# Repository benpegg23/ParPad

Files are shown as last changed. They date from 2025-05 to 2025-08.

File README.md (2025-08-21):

# ⛳ ParPad

**ParPad** is an STM32-based macropad featuring a 3×3 layout and two rotary encoders. Custom firmware coming soon! 

## 🔧 Features

- 3×3 mechanical key matrix
- Dual EC11 rotary encoders with push functionality
- Cherry MX switch support
- USB-C connectivity
- STM32F072C8T6 Microcontroller
- Custom firmware (coming soon)

## 📸 Images

parpadbannersidestuff
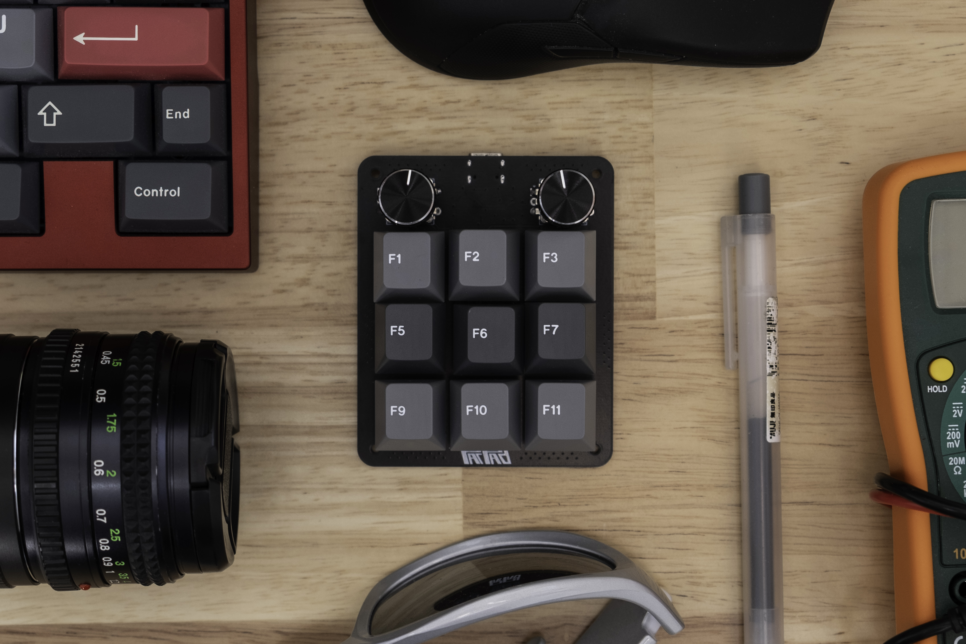
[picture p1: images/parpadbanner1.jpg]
parpadbanner1

parpad1
parpadbelow
parpad_down
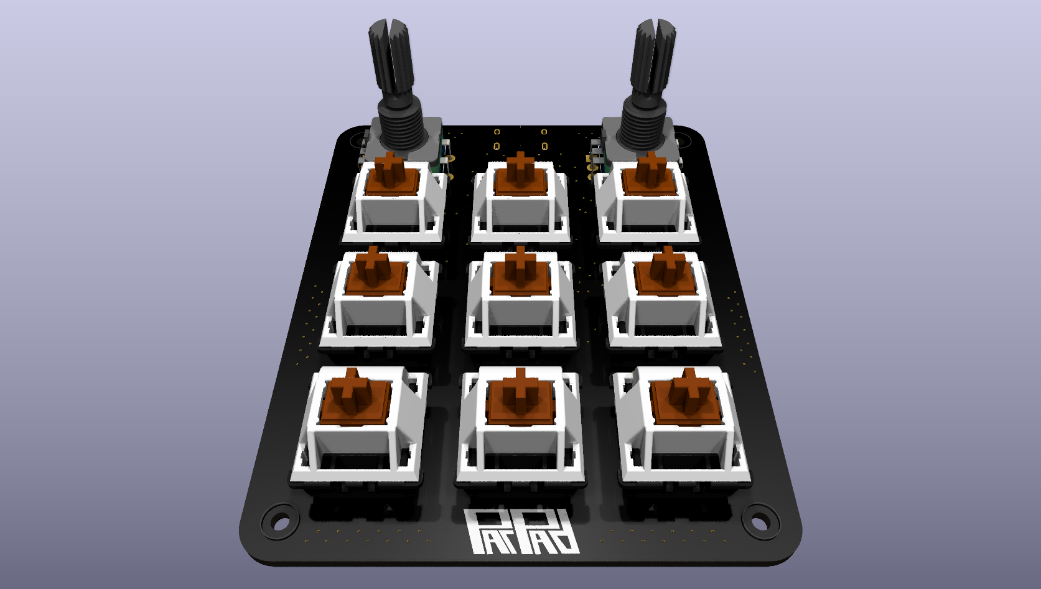
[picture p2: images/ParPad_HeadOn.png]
ParPad_HeadOn

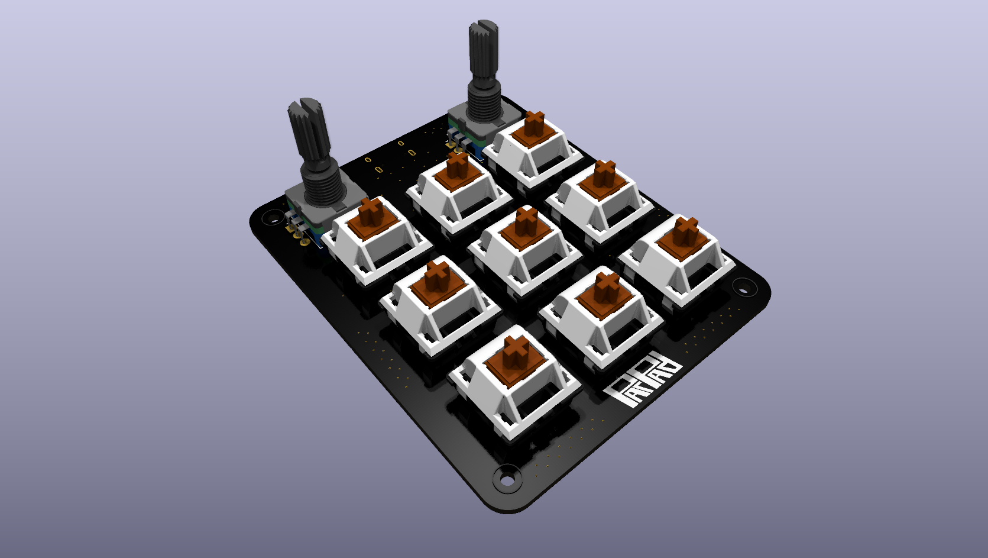
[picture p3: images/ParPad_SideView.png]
ParPad_SideView

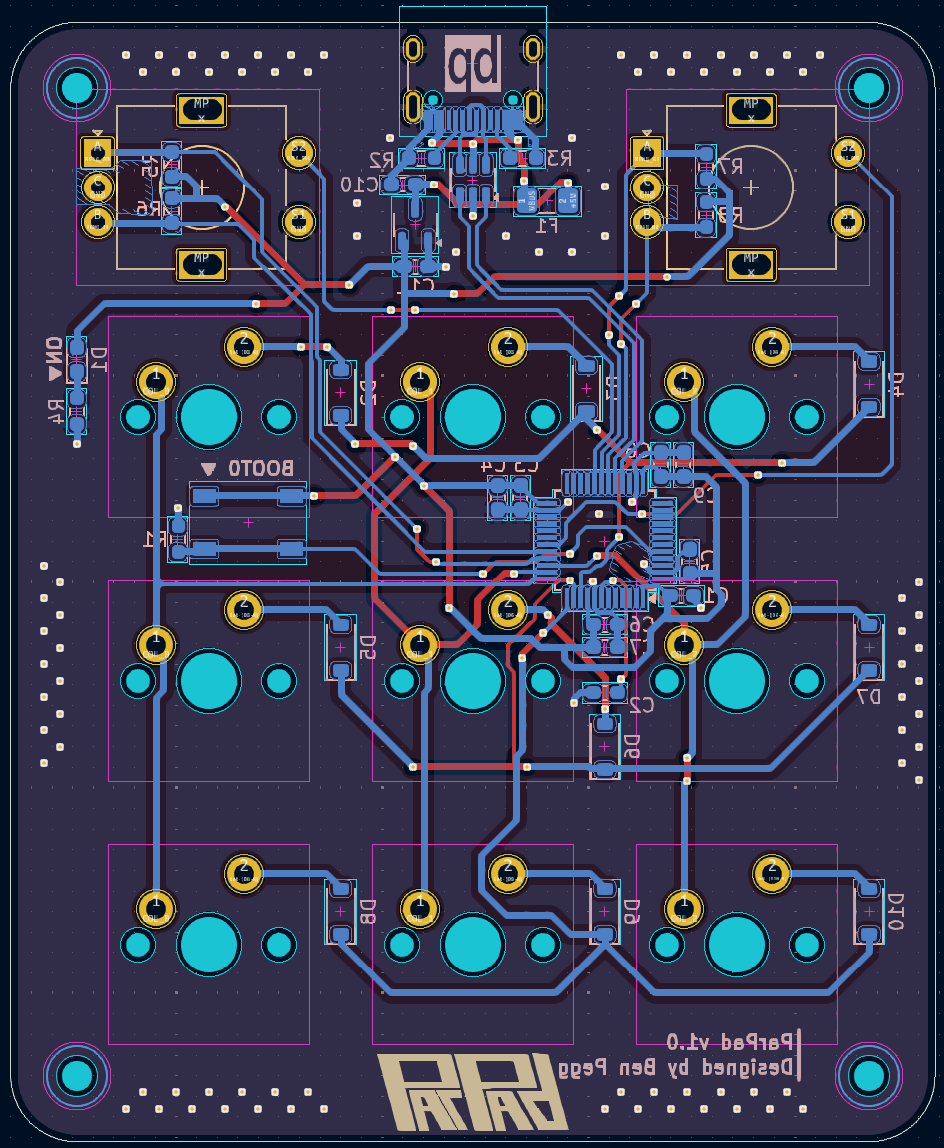
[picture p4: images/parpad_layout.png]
parpad_layout


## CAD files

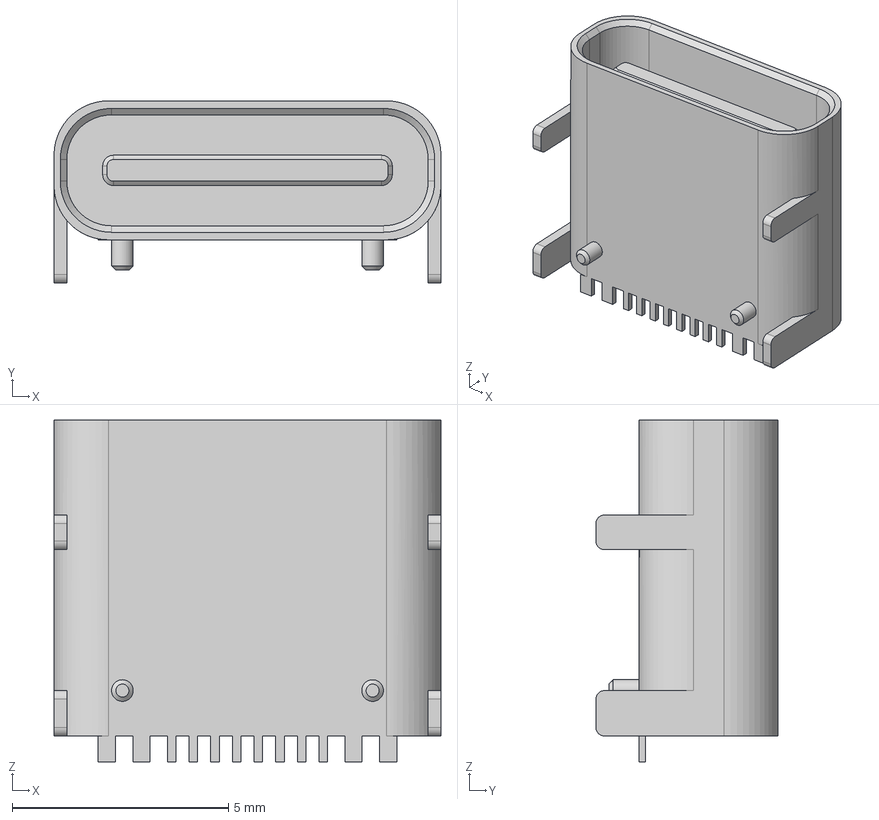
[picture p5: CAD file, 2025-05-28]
hardware/macropad_v1.0/3d_models/HRO TYPE-C-31-M-12_ai03.step
8.94 x 4.21 x 7.90 mm

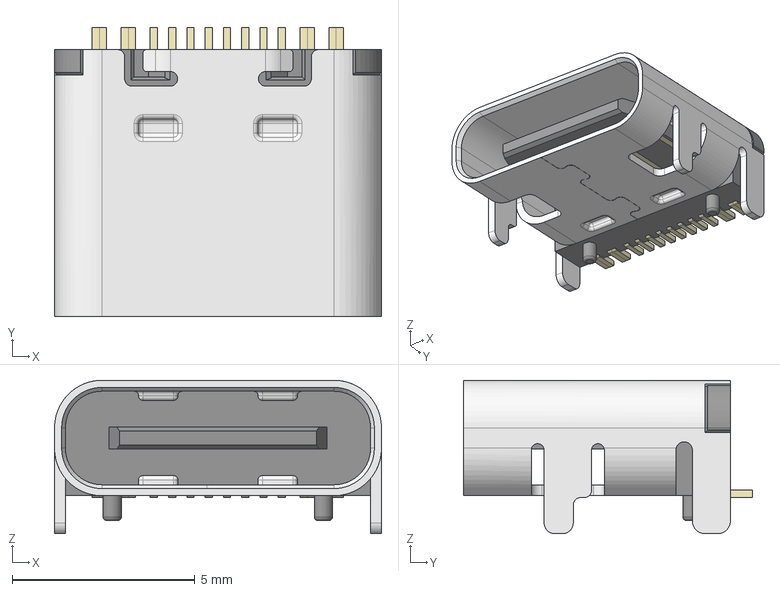
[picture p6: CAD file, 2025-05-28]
hardware/macropad_v1.0/3d_models/HRO_TYPE-C-31-M-12.step
8.95 x 7.90 x 4.20 mm

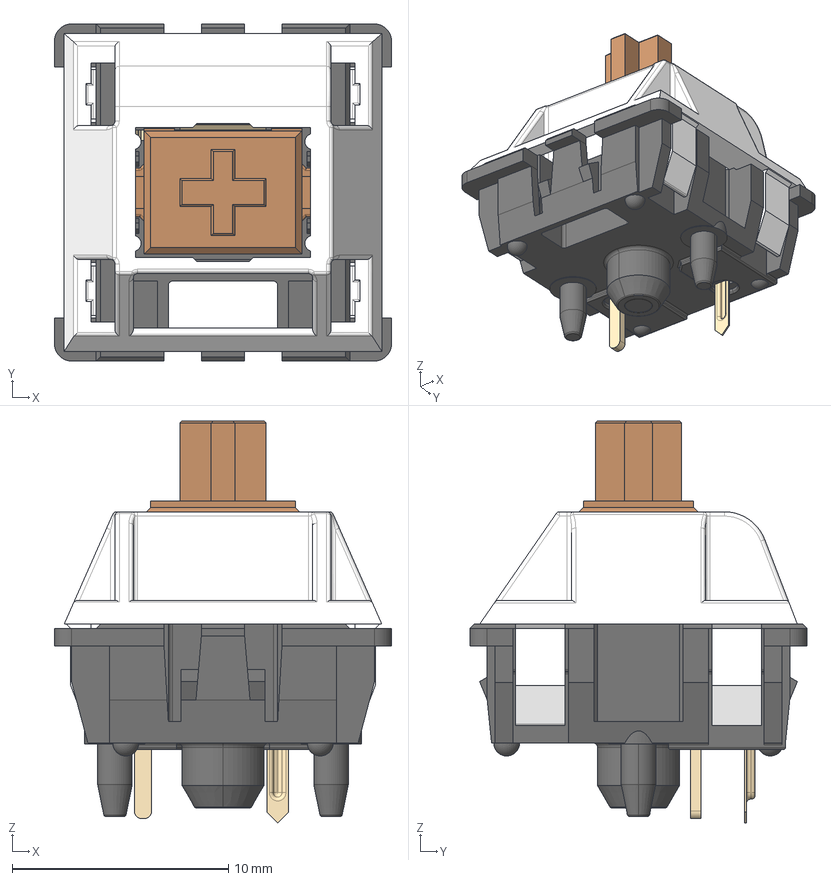
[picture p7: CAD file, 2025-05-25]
hardware/macropad_v1.0/3d_models/MX_PCB.step
15.6 x 15.6 x 18.6 mm

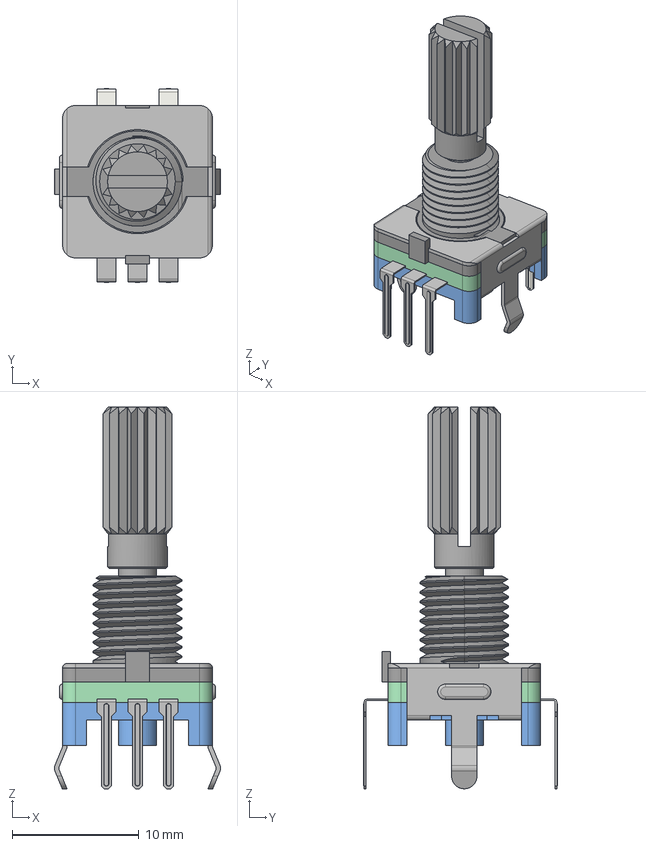
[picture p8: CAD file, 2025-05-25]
hardware/macropad_v1.0/3d_models/EC11_Rotary_Encoder_Switched.step
13.1 x 15.3 x 30.1 mm

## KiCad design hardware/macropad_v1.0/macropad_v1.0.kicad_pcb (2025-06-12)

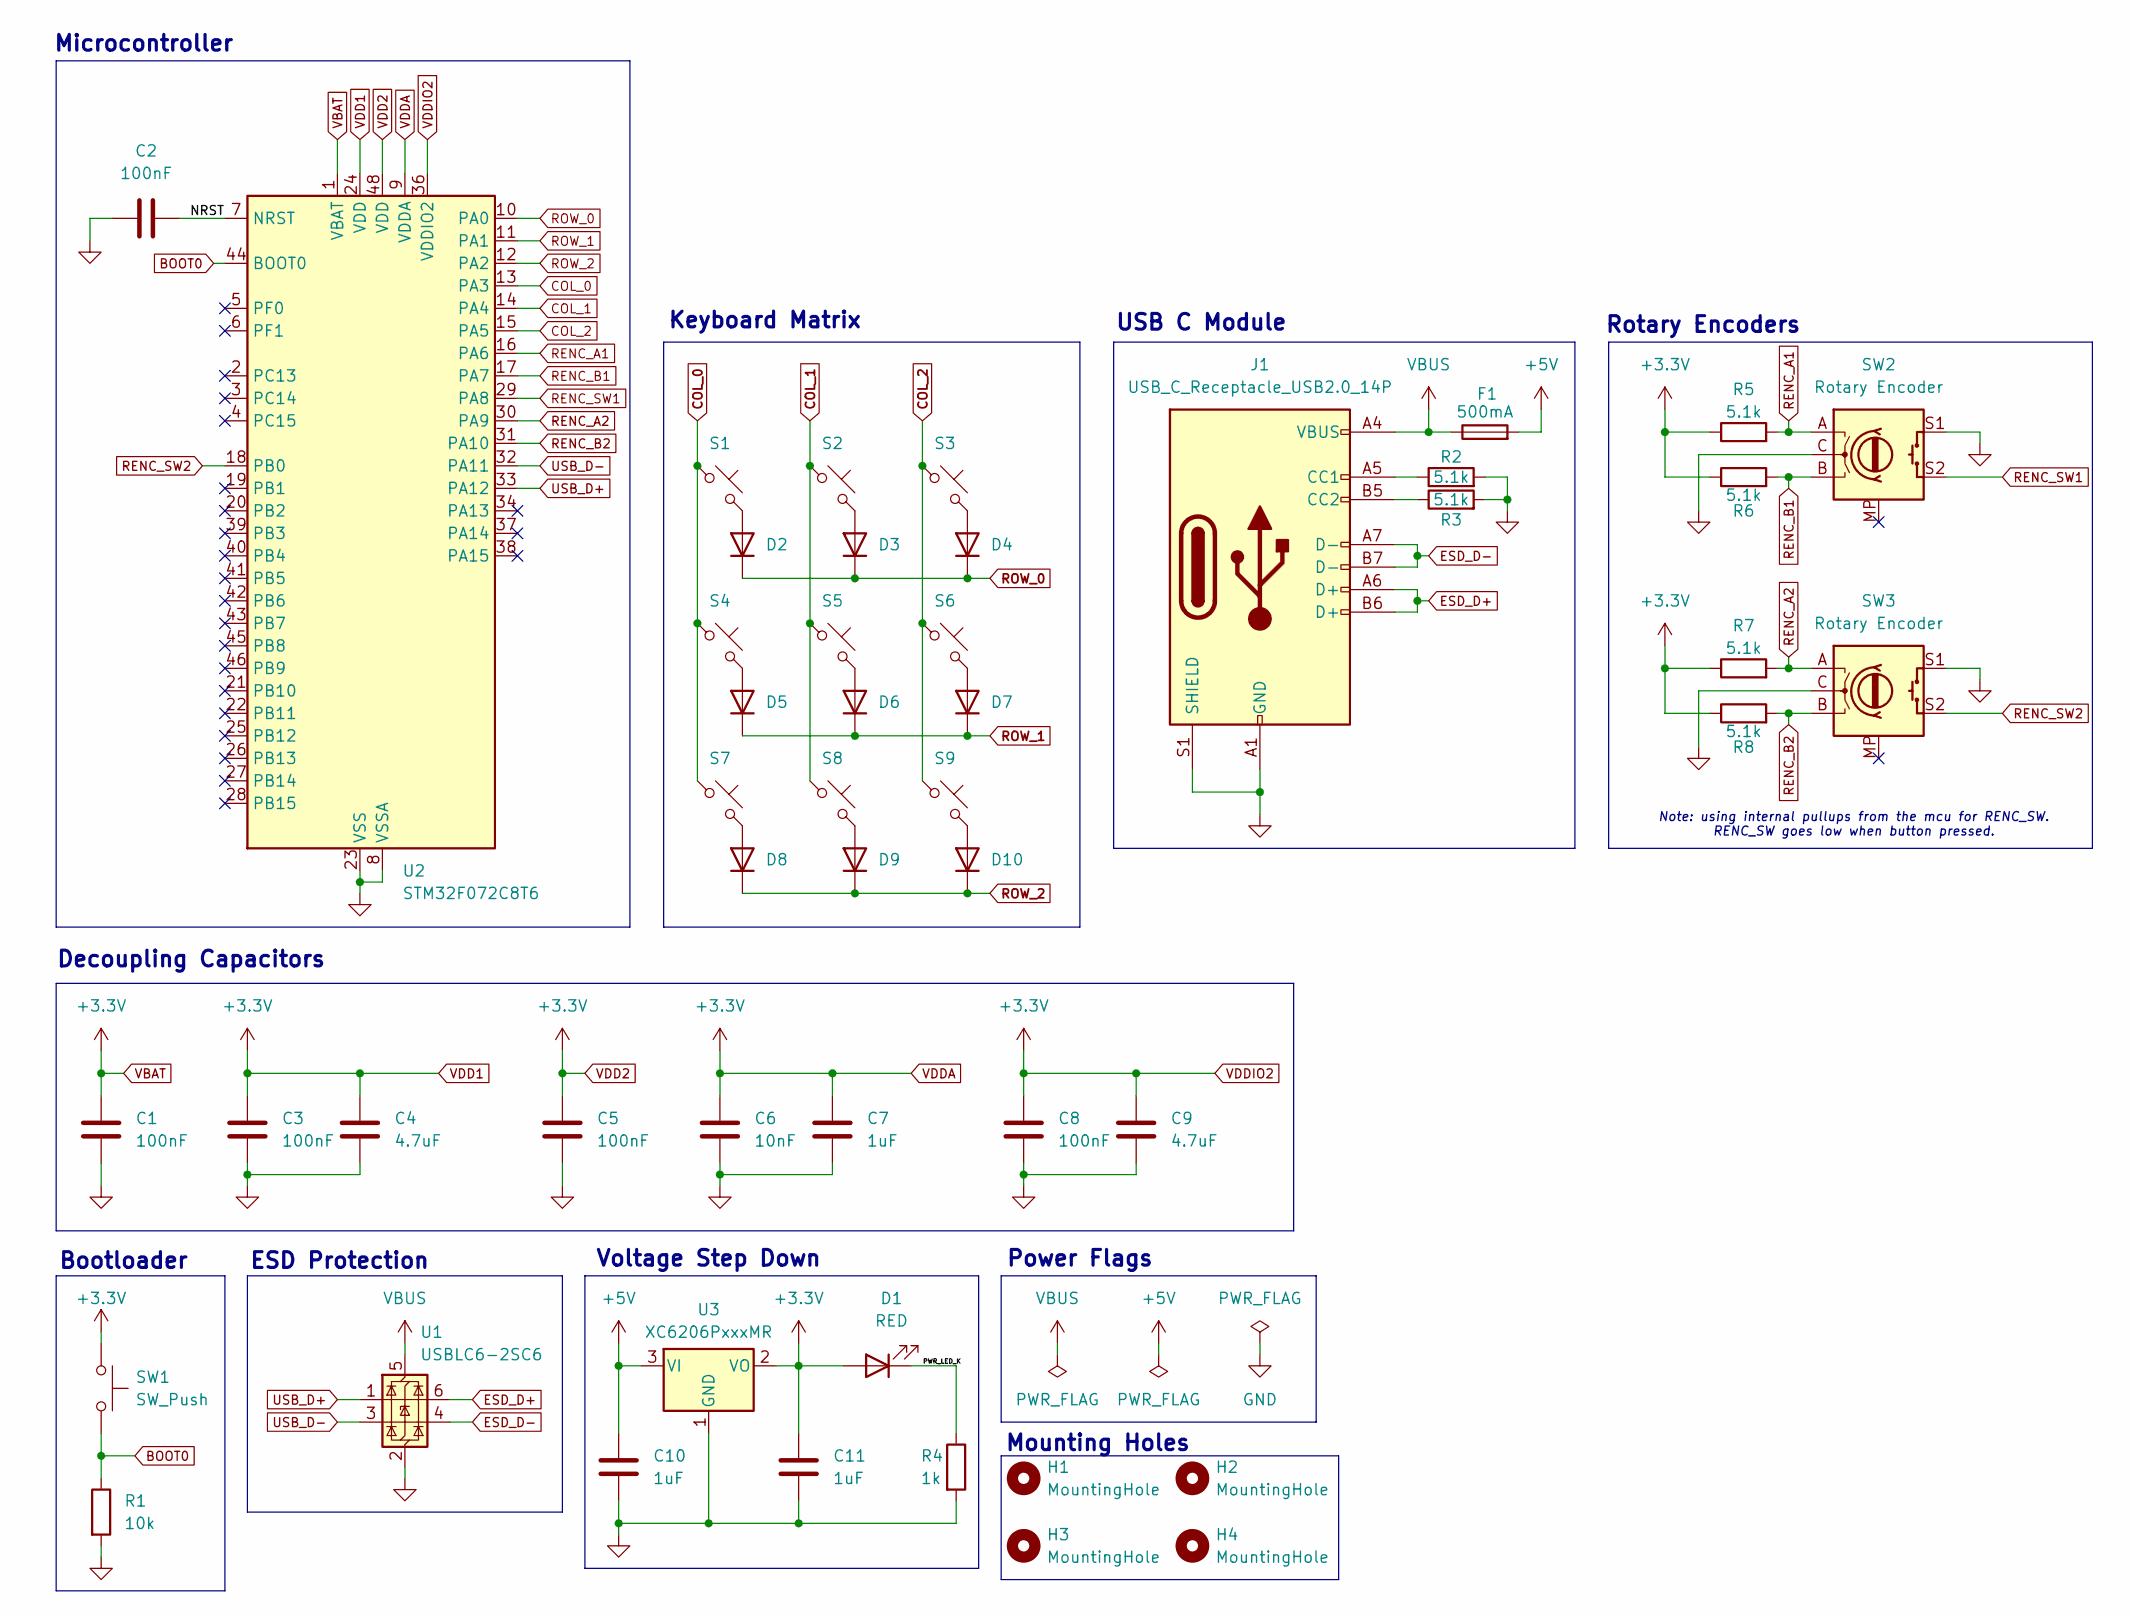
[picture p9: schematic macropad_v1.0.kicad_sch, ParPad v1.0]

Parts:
C1, C2, C3, C5, C8: 100nF; C_0603_1608Metric_Pad1.08x0.95mm_HandSolder
C4, C9: 4.7uF; C_0603_1608Metric_Pad1.08x0.95mm_HandSolder
C6: 10nF; C_0603_1608Metric_Pad1.08x0.95mm_HandSolder
C7, C10, C11: 1uF; C_0603_1608Metric_Pad1.08x0.95mm_HandSolder
D1: RED; LED_0603_1608Metric_Pad1.05x0.95mm_HandSolder
D2, D3, D4, D5, D6, D7, D8, D9, D10: 1N4148W; D_SOD-123
F1: 500mA; Fuse_1206_3216Metric_Pad1.42x1.75mm_HandSolder
H1, H2, H3, H4: MountingHole; MountingHole_2.2mm_M2
J1: USB_C_Receptacle_USB2.0_14P; USB_C_Receptacle_HRO_TYPE-C-31-M-12
R1: 10k; R_0603_1608Metric_Pad0.98x0.95mm_HandSolder
R2, R3, R5, R6, R7, R8: 5.1k; R_0603_1608Metric_Pad0.98x0.95mm_HandSolder
R4: 1k; R_0603_1608Metric_Pad0.98x0.95mm_HandSolder
S1, S2, S3, S4, S5, S6, S7, S8, S9: Keyswitch; MX_PCB_1.00u
SW1: SW_Push; Button_TL3342
SW2, SW3: Rotary Encoder; RotaryEncoder_Alps_EC11E-Switch_Vertical_H20mm
U1: USBLC6-2SC6; SOT-23-6
U2: STM32F072C8T6; LQFP-48_7x7mm_P0.5mm
U3: XC6206PxxxMR; SOT-23-3

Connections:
+5V: C10.1, F1.2, U3.3 (VI)
/NRST: C2.2, U2.7 (NRST)
/PWR_LED_K: D1.1 (K), R4.1
BOOT0: R1.1, SW1.2, U2.44 (BOOT0)
COL_0: S1.1, S4.1, S7.1, U2.13 (PA3)
COL_1: S2.1, S5.1, S8.1, U2.14 (PA4)
COL_2: S3.1, S6.1, S9.1, U2.15 (PA5)
ESD_D+: J1.A6 (D+), J1.B6 (D+), U1.6 (I/O1)
ESD_D-: J1.A7 (D-), J1.B7 (D-), U1.4 (I/O2)
GND: C1.2, C2.1, C3.2, C4.2, C5.2, C6.2, C7.2, C8.2, C9.2, C10.2, C11.2, J1.A1 (GND), J1.A12 (GND), J1.B1 (GND), J1.B12 (GND), J1.S1 (SHIELD), R1.2, R2.2, R3.2, R4.2, SW2.C, SW2.S1, SW3.C, SW3.S1, U1.2 (GND), U2.8 (VSSA), U2.23 (VSS), U2.35 (VSS), U2.47 (VSS), U3.1 (GND)
unnamed: D2.2 (A), S1.2
unnamed: D3.2 (A), S2.2
unnamed: D4.2 (A), S3.2
unnamed: D5.2 (A), S4.2
unnamed: D6.2 (A), S5.2
unnamed: D7.2 (A), S6.2
unnamed: D8.2 (A), S7.2
unnamed: D9.2 (A), S8.2
unnamed: D10.2 (A), S9.2
unnamed: J1.A5 (CC1), R2.1
unnamed: J1.B5 (CC2), R3.1
RENC_A1: R5.2, SW2.A, U2.16 (PA6)
RENC_A2: R7.2, SW3.A, U2.30 (PA9)
RENC_B1: R6.2, SW2.B, U2.17 (PA7)
RENC_B2: R8.2, SW3.B, U2.31 (PA10)
RENC_SW1: SW2.S2, U2.29 (PA8)
RENC_SW2: SW3.S2, U2.18 (PB0)
ROW_0: D2.1 (K), D3.1 (K), D4.1 (K), U2.10 (PA0)
ROW_1: D5.1 (K), D6.1 (K), D7.1 (K), U2.11 (PA1)
ROW_2: D8.1 (K), D9.1 (K), D10.1 (K), U2.12 (PA2)
USB_D+: U1.1 (I/O1), U2.33 (PA12)
USB_D-: U1.3 (I/O2), U2.32 (PA11)
VBAT: C1.1, C3.1, C4.1, C5.1, C6.1, C7.1, C8.1, C9.1, C11.1, D1.2 (A), R5.1, R6.1, R7.1, R8.1, SW1.1, U2.1 (VBAT), U2.9 (VDDA), U2.24 (VDD), U2.36 (VDDIO2), U2.48 (VDD), U3.2 (VO)
VBUS: F1.1, J1.A4 (VBUS), J1.A9 (VBUS), J1.B4 (VBUS), J1.B9 (VBUS), U1.5 (VBUS)

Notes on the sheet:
Note: using internal pullups from the mcu for RENC_SW. RENC_SW goes low when button pressed.
Voltage Step Down
Keyboard Matrix
Bootloader
Rotary Encoders
Decoupling Capacitors
ESD Protection
Power Flags
USB C Module
Mounting Holes
Microcontroller

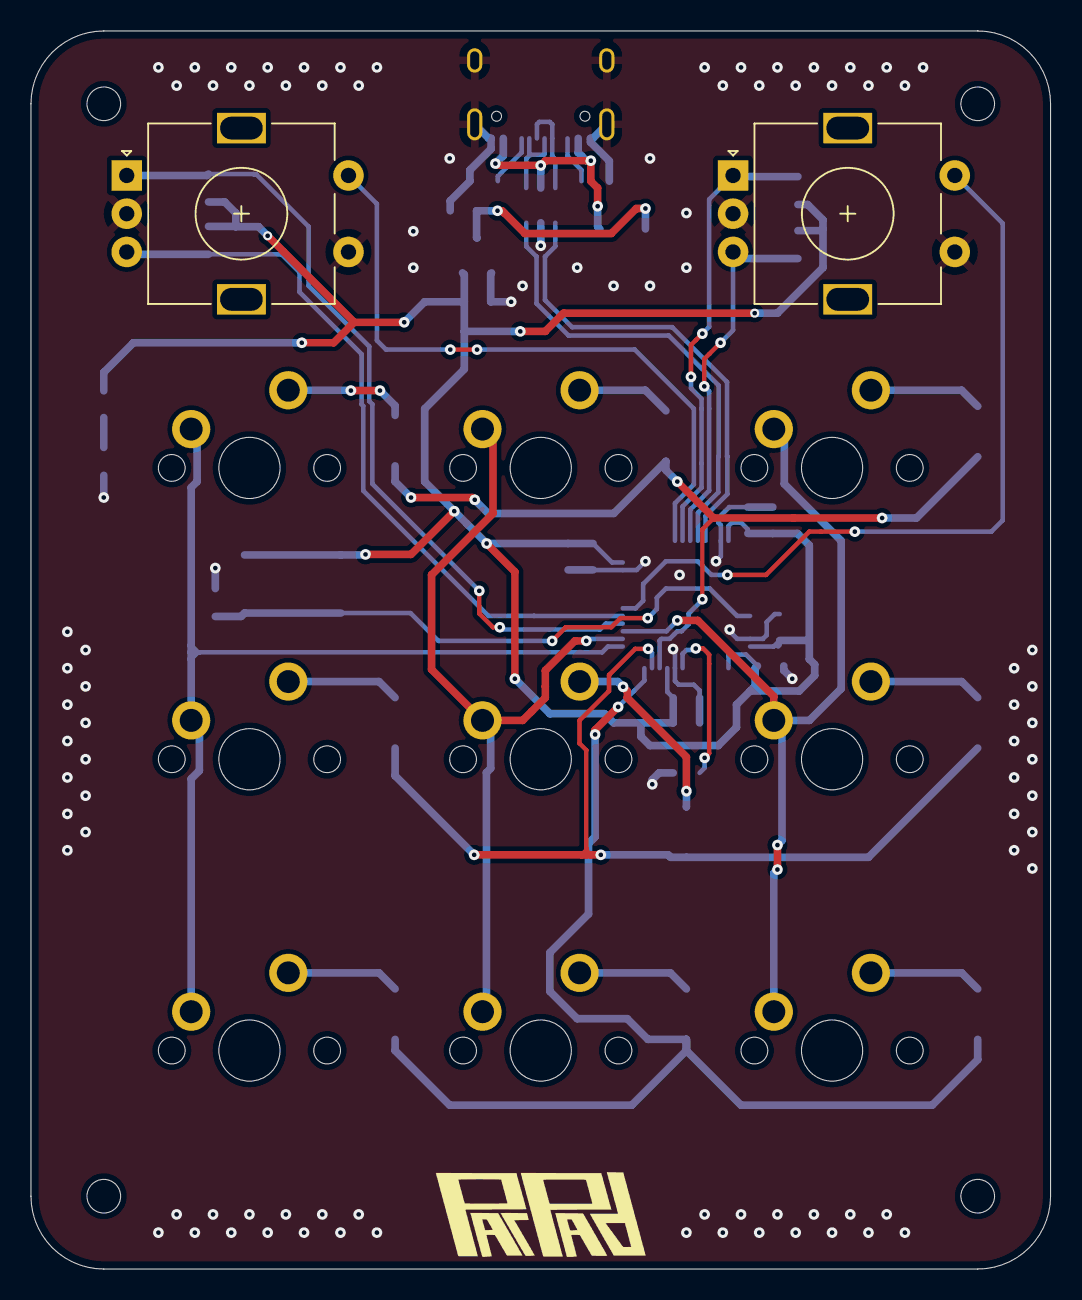
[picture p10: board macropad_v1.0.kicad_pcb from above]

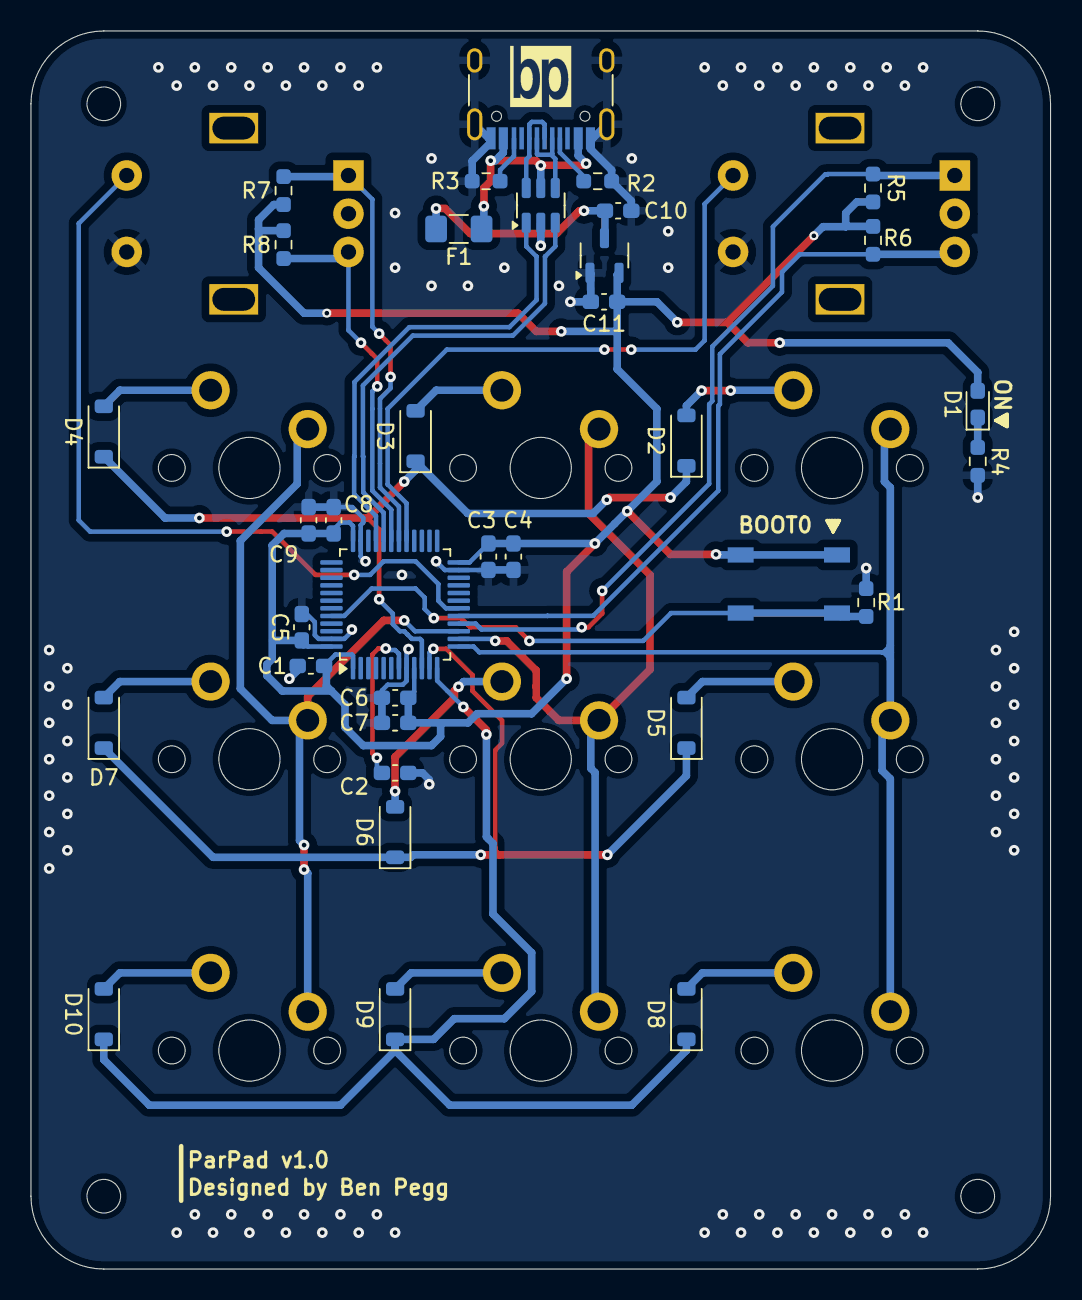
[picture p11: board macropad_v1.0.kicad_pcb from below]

Board: 2 copper layers, 66.7 x 81.0 mm, 50 parts (35 on the bottom side), 34 nets.

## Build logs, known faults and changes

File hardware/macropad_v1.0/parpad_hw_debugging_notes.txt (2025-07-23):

Issues when assembling:
- 3v3 led indicator turns on for a split second when connecting, and then shuts off. Probing reveals that the board is receiving 5v correctly, but something is happening with the voltage regulator, because Vout is around 0.5v instead of the expected 3v3. 
--Potential Reasons: 
--datasheet config shows diodes included on 3v3 and 5v sides, but iirc they're not essential?
--probably a short somewhere that's connecting 3v3 and gnd
--if can't find short, try replacing voltage regulator unit
- Definitely a short somewhere, when doing a continuity test between ground and 3v3 output of voltage regulator, getting a beep. Also lifehack, you can use the outside of the usb connector as a ground reference. 
- Tried to find short using the resistance method thing where you measure the resistance between gnd and 3v3 path. Apparently the resistance is supposed to decrease when you're getting closer to the short, but when measuring it, all of the resistance measurements were the same across the whole 3v3 path. Probably because my multimeter isn't accurate enough to find the small changes, would need a bench multimeter. 
- Best way to find a short is to use a bench power supply, which I obviously don't have
-- Connect power supply, set to ~1-2V, set current to around 5-10A, attach to 3v3 rail, then see which component gets hot
-- Can either use finger, isopropyl alcohol (see where evaporates first), or thermal camera
- Other way is to just desolder components until you find the short, which is prob what I'll have to do cuz I otherwise I have to wait a month until I get back to school.

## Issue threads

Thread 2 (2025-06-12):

find a usb-c receptacle

benpegg23, 2025-06-12:
I need a hand solderable usb-c receptacle that isn't hella expensive and matches the footprint of the HRO version cuz digikey doesn't have it 😔

Closed 2025-06-14.

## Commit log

2025-05-25 pushing initial design of schematic, updated project file structure
    [EC11_Rotary_Encoder_Switched.step, MX_PCB.step, macropad_v1.0.kicad_pcb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]
2025-05-27 added second rotary encoder, made progress on layout
    [macropad_v1.0.kicad_pcb, macropad_v1.0.kicad_sch]
2025-05-27 finished routing decoupling caps & usb-c module
    [macropad_v1.0.kicad_pcb]
2025-05-28 updated some 3d models, finished routing usb and esd protection
    [HRO TYPE-C-31-M-12_ai03.step, HRO_TYPE-C-31-M-12.step, macropad_v1.0.kicad_pcb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]
2025-05-28 finished routing everything except gnd and a few diodes
    [macropad_v1.0.kicad_pcb]
2025-05-29 routed a bunch of stuff but realized all my vias were the wrong size so I still have to reroute oops
    [macropad_v1.0.kicad_pcb]
2025-06-02 Deleted old routing, redoing routing
    -Rotated MCU so that datalines are facing upwards towards USB-C receptacle
    -Made sure decoupling capacitors were routed to correct pins on MCU (they weren't before)
    -Corrected minimum via sizing to match JLCPCB rules
    -Cleaned up routing for USB-C receptacle to ESD protection unit to avoid interference from 5V line
    -Next steps should be routing voltage step down so that I can route all the Vdd pins (3.3V)
    [macropad_v1.0.kicad_pcb]
2025-06-02 Routed voltage step down
    [macropad_v1.0.kicad_pcb]
2025-06-04 Finished PCB design
    -Routed everything
    -Added a gnd plane to top layer
    Next Steps:
    -Make sure traces are wide enough
    -Move all the silkscreen stuff
    -Check for interference around voltage line
    -Check that ground plane is fine
    -Resolve the rest of the DRC errors/warnings
    [macropad_v1.0.kicad_pcb]
2025-06-05 Finalized Silkscreen
    -Made sure references weren't interfering with pads/vias/etc.
    -Added BP logo to front
    -Moved trace to decap slightly so that it wasn't interfering with mcu silkscreen
    -Added BOOT0 and ON designators to boot button and on diode
    -Added name and designed by to back silkscreen
    [macropad_v1.0.kicad_pcb]
2025-06-09 Changed USB-C routing
    -Changed routing from usb-c module to esd protection module by shorting the pair of D+ and D- pins. New routing doesn't use a via, has shorter traces from usb module to esd module, and matches the length of the traces for D+ and D- better than the previous design did.
    -Increased the width of the differential pair data traces from esd module to mcu from 0.2mm to 0.3mm to match traces that go into the esd module. Kicad made them 0.2mm by default for some reason.
    -Next steps: change the routing near the MCU to eliminate overuse of vias, add a ground plane to the bottom layer and add stitching vias to connect the two planes
    [macropad_v1.0.kicad_pcb]
2025-06-10 Changed routing
    -Edited traces to avoid overusing vias
    -Next steps: Add stitching vias to connect the two ground planes
    [macropad_v1.0.kicad_pcb]
2025-06-10 Added stitching vias
    -Next steps: upload files to jlcpcb, generate a bom, figure out what I'm going to hand-solder, and order everything
    [macropad_v1.0.kicad_pcb]
2025-06-10 Updated silkscreen and naming stuff, added keepouts
    -Added ParPad logo to fron silkscreen
    -Changed the name of the design in the little design box in the bottom right of the pcb and schematic
    -Added two keepout zones to certain areas of the bottom ground fill to avoid an error about thermal spokes (only had one spoke, just got rid of the spoke cuz the top ground layer already has four spokes), and also a warning about some copper thing being too narrow
    [macropad_v1.0.kicad_pcb]
2025-06-10 forgot to save schematic
    -exact changes can be found in old commit, I think it was just changing the name in the title block to say ParPad
    [macropad_v1.0.kicad_sch]
2025-06-12 Updated stuff according to jlcpcb specifications and added production files
    -Moved the resistors connected to the rotary encoder pins to be further away cuz jlcpcb was mad about tht to smd pad clearance
    -added some more keepouts to bottom gnd plane to get rid of some drc errors about thermal spokes and stuff
    -Moved a via near one of the encoders cuz it was overlapping the silkscreen
    -Moved a couple designators cuz they overlapped with vias
    -Moved C1 (decoupling cap) cuz it was too close to one of the through holes for the switch pins
    -Changed bottom silkscreen to say ParPad instead of PARpad
    -Added production files (bom, placements, gerbers, etc. idrk what else is in there tbh)
    [macropad_v1.0.kicad_pcb]
